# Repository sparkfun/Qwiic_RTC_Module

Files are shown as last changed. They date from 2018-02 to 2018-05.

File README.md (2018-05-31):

Qwiic Real Time Clock Module (RV-1805) Module
==================

Real Time Clock Module

[*Qwiic RV-1805 RTC Module (BOB-14558)*](https://www.sparkfun.com/products/14558)

Get with the times, already! This SparkFun Real Time Clock (RTC) Module is a Qwiic-enabled breakout board for the RV-1805 chipset. The RTC is ultra-low power (running at only about 22nA in its lowest power setting) so it can use a supercapacitor for backup power instead of a normal battery. This means you get plenty of charge and discharge cycles without any degradation to the “battery.“ To make it even easier to get your readings, all communication is enacted exclusively via I2C, utilizing our handy Qwiic system so no soldering is required to connect it to the rest of your system. However, we still have broken out 0.1”-spaced pins in case you prefer to use a breadboard.

Repository Contents
-------------------
* **/Documents** - Datasheets. 
* **/Hardware** - All Eagle design files (.brd, .sch). 
* **/Production** - Various test jigs and large panel layouts used for production.

Documentation
--------------
* **[Library](https://github.com/sparkfun/SparkFun_RV-1805_Arduino_Library)** - Arduino library for the Qwiic Real Time Clock Module (RV-1805) Module.
* **[Hookup Guide](https://learn.sparkfun.com/tutorials/qwiic-real-time-clock-module-rv-1805-hookup-guide)** - Basic hookup guide.

Product Versions
----------------
* [BOB-14558](https://www.sparkfun.com/products/14558) - SparkFun red version
* [SPX-14642](https://www.sparkfun.com/products/14642) - SparkX version

License Information
-------------------

This product is _**open source**_! 

Please review the LICENSE.md file for license information. 

If you have any questions or concerns on licensing, please contact techsupport@sparkfun.com.

Distributed as-is; no warranty is given.

- Your friends at SparkFun.

_<COLLABORATION CREDIT>_

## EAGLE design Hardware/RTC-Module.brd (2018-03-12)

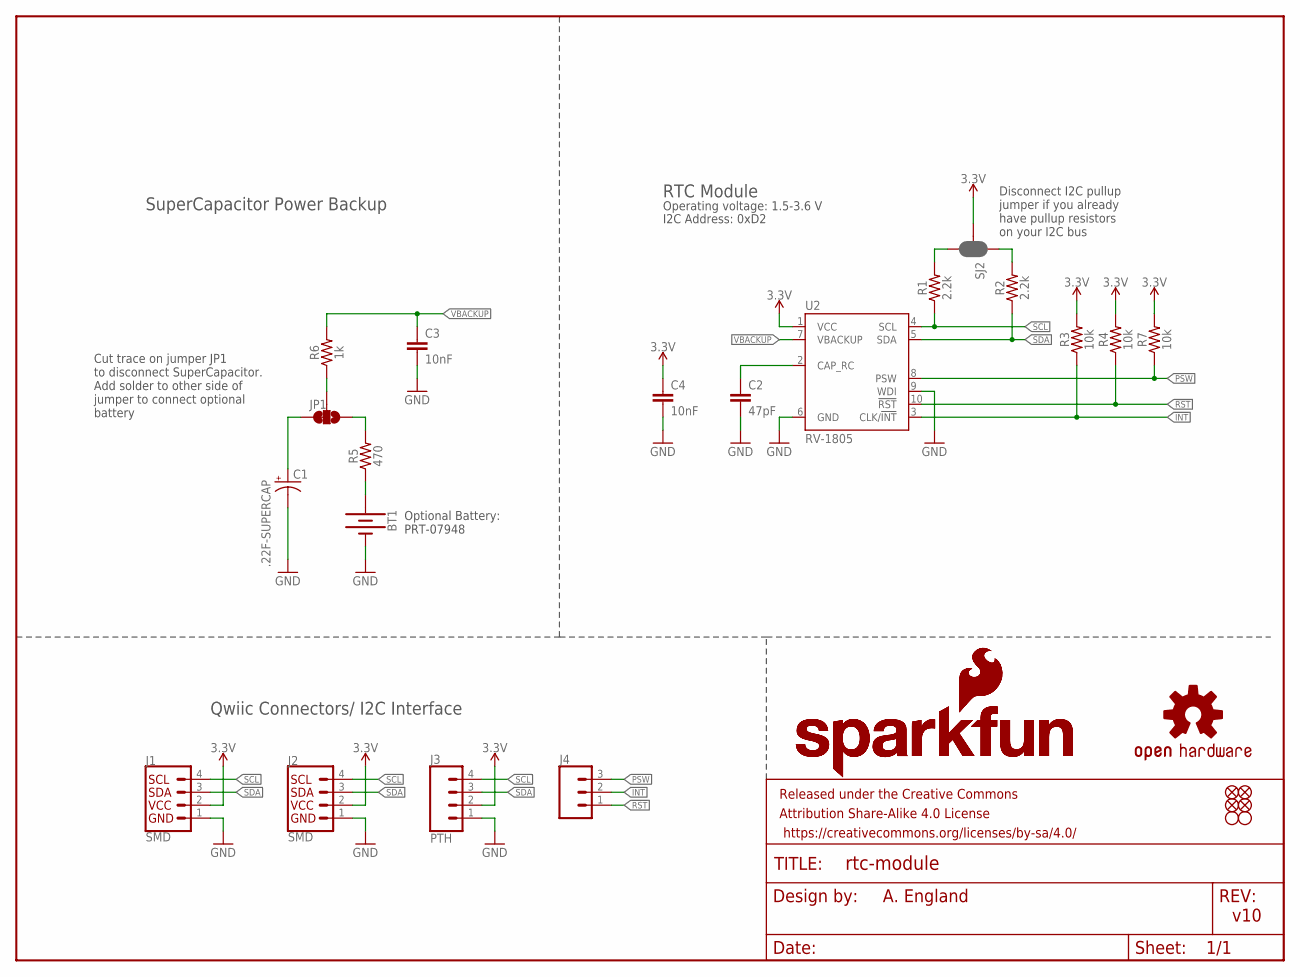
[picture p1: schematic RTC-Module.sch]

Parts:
BT1: BATTERY-12MM_PTH; BATTCON_12MM_PTH
C1: .22F-SUPERCAP; DSK-RADIAL-6.8MM
C2: 47pF; 0603
C3, C4: 10nF; 0603
FD1, FD2, FD3, FD4: FIDUCIALUFIDUCIAL; FIDUCIAL-MICRO
FRAME2: FRAME-LETTER; CREATIVE_COMMONS
J1, J2: SMD; 1X04_1MM_RA
J3: PTH; 1X04_NO_SILK
J4: CONN_031X03_NO_SILK; 1X03_NO_SILK
JP1: JUMPER-SMT_3_1-NC_TRACE_NO-SILK; SMT-JUMPER_3_1-NC_TRACE_NO-SILK
LOGO1: OSHW-LOGOS; OSHW-LOGO-S
LOGO2, LOGO3: SFE_LOGO_NAME_FLAME.1_INCH; SFE_LOGO_NAME_FLAME_.1
R1, R2: 2.2k; 0603
R3, R4, R7: 10k; 0603
R5: 470; 0603
R6: 1k; 0603
SJ2: JUMPER-SMT_3_2-NC_PASTE_SILK; SMT-JUMPER_3_2-NC_PASTE_SILK
U2: RV-1805
U$6, U$7: STAND-OFF

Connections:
3.3V: C4.1, J1.2, J2.2, J3.2, R3.2, R4.2, R7.2, SJ2.2, U2.1 (VCC)
!INT: J4.2, R3.1, U2.3 (CLK/!INT)
!RST: J4.1, R4.1, U2.10 (!RST)
GND: BT1.GND (-), C1.-, C2.2, C3.2, C4.2, J1.1, J2.1, J3.1, U2.6 (GND), U2.9 (WDI)
unnamed: R1.2, SJ2.3
unnamed: R2.2, SJ2.1
unnamed: BT1.VCC@1 (+), R5.1
unnamed: C2.1, U2.2 (CAP_RC)
unnamed: JP1.2, R6.1
unnamed: C1.+, JP1.3
unnamed: JP1.1, R5.2
PSW: J4.3, R7.1, U2.8 (PSW)
SCL: J1.4, J2.4, J3.4, R1.1, U2.4 (SCL)
SDA: J1.3, J2.3, J3.3, R2.1, U2.5 (SDA)
VBACKUP: C3.1, R6.2, U2.7 (VBACKUP)

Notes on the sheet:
v10
A. England
SuperCapacitor Power Backup
RTC Module
Qwiic Connectors/ I2C Interface
Cut trace on jumper JP1 to disconnect SuperCapacitor. Add solder to other side of jumper to connect optional battery
Operating voltage: 1.5-3.6 V
Disconnect I2C pullup jumper if you already have pullup resistors on your I2C bus
I2C Address: 0xD2
Optional Battery: PRT-07948

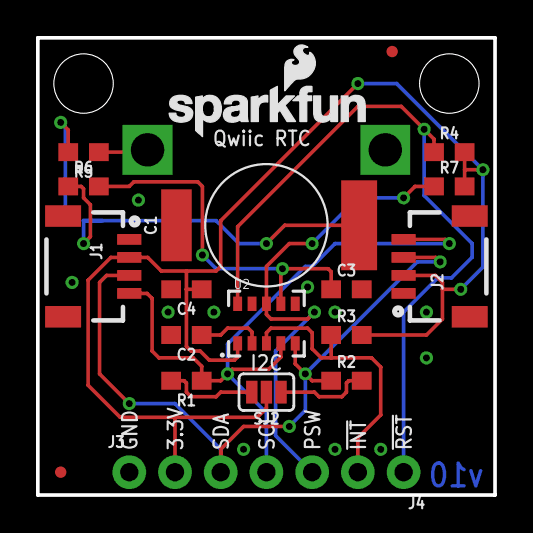
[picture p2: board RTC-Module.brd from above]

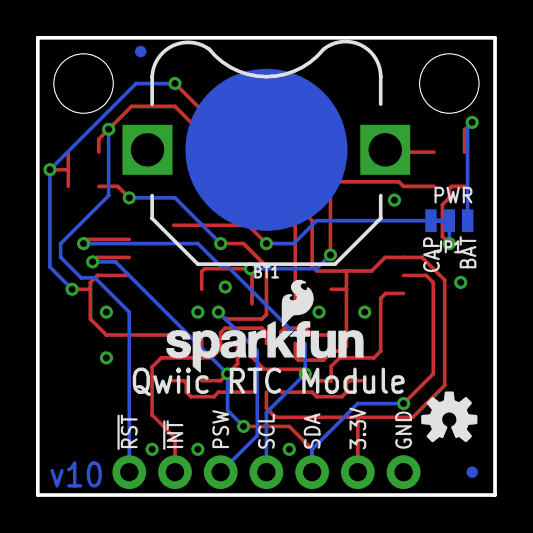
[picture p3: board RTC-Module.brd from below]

Board: 2 copper layers, 25.4 x 25.4 mm, 29 parts (6 on the bottom side), 15 nets.

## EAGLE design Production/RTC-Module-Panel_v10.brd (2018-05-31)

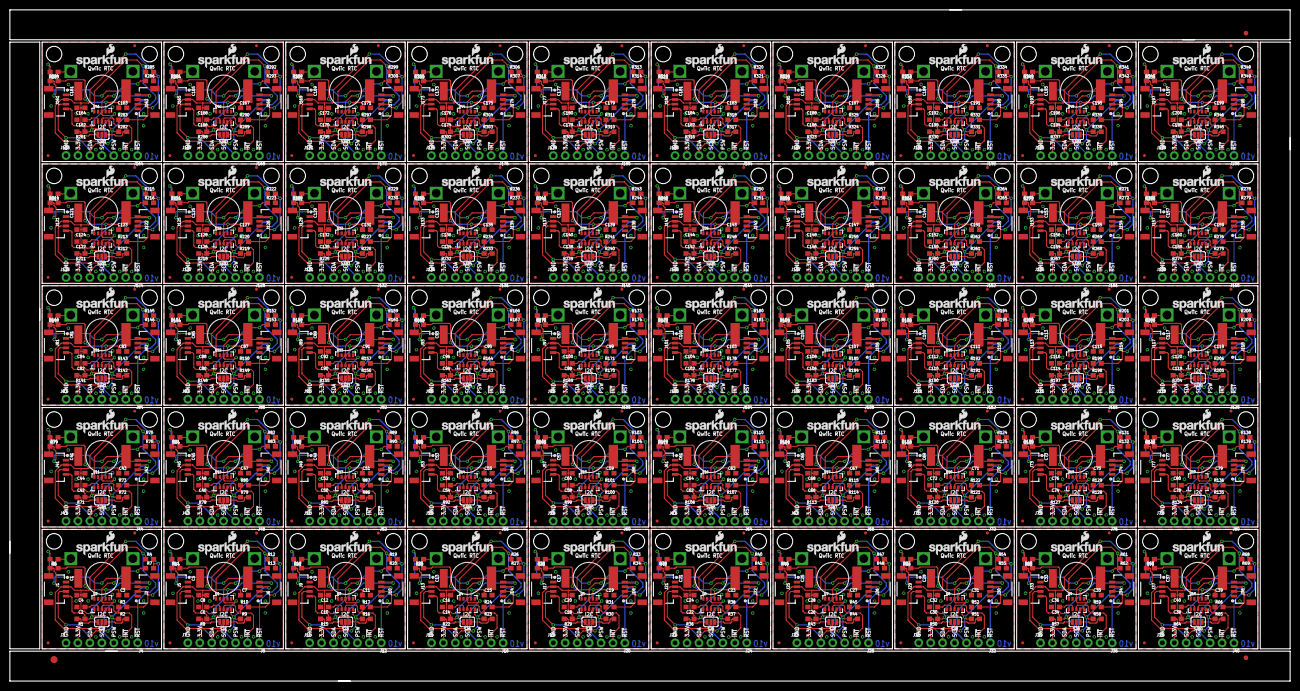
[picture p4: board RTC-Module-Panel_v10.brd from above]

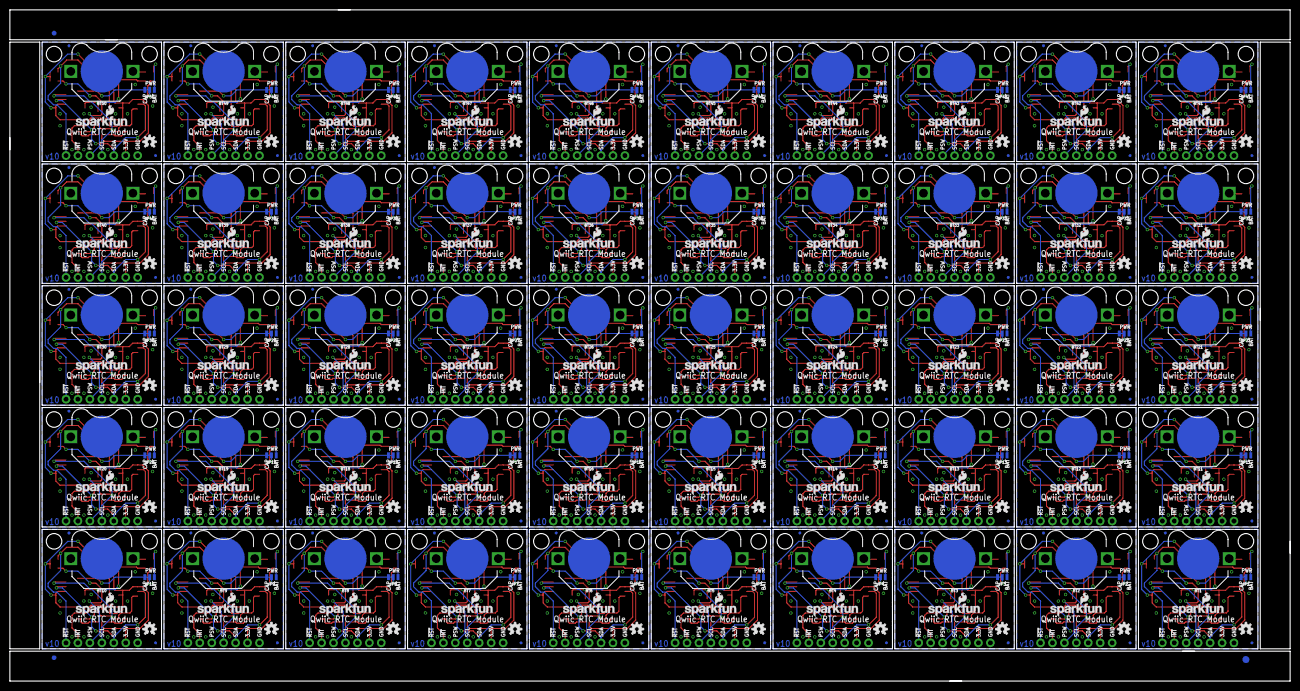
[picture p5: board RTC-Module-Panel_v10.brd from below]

Board: 2 copper layers, 272.3 x 142.7 mm, 1406 parts (303 on the bottom side), 750 nets.

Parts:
BT1, BT2, BT3, BT4, BT5, BT6, BT7, BT8, BT9, BT10, BT11, BT12, BT13, BT14, BT15, BT16, BT17, BT18, BT19, BT20, BT21, BT22, BT23, BT24, BT25, BT26, BT27, BT28, BT29, BT30, BT31, BT32, BT33, BT34, BT35, BT36, BT37, BT38, BT39, BT40, BT41, BT42, BT43, BT44, BT45, BT46, BT47, BT48, BT49, BT50: BATTCON_12MM_PTH
C1, C5, C9, C13, C17, C21, C25, C29, C33, C37, C41, C45, C49, C53, C57, C61, C65, C69, C73, C77, C81, C85, C89, C93, C97, C101, C105, C109, C113, C117, C121, C125, C129, C133, C137, C141, C145, C149, C153, C157, C161, C165, C169, C173, C177, C181, C185, C189, C193, C197: .22F-SUPERCAP; DSK-RADIAL-6.8MM
C2, C6, C10, C14, C18, C22, C26, C30, C34, C38, C42, C46, C50, C54, C58, C62, C66, C70, C74, C78, C82, C86, C90, C94, C98, C102, C106, C110, C114, C118, C122, C126, C130, C134, C138, C142, C146, C150, C154, C158, C162, C166, C170, C174, C178, C182, C186, C190, C194, C198: 47pF; 0603
C3, C4, C7, C8, C11, C12, C15, C16, C19, C20, C23, C24, C27, C28, C31, C32, C35, C36, C39, C40, C43, C44, C47, C48, C51, C52, C55, C56, C59, C60, C63, C64, C67, C68, C71, C72, C75, C76, C79, C80, C83, C84, C87, C88, C91, C92, C95, C96, C99, C100, C103, C104, C107, C108, C111, C112, C115, C116, C119, C120, C123, C124, C127, C128, C131, C132, C135, C136, C139, C140, C143, C144, C147, C148, C151, C152, C155, C156, C159, C160, C163, C164, C167, C168, C171, C172, C175, C176, C179, C180, C183, C184, C187, C188, C191, C192, C195, C196, C199, C200: 10nF; 0603
E$1, E$2: FIDUCIAL-1.5X3
E$3, E$4, E$6, E$7: FIDUCIAL-1X2
FD1, FD2, FD3, FD4, FD5, FD6, FD7, FD8, FD9, FD10, FD11, FD12, FD13, FD14, FD15, FD16, FD17, FD18, FD19, FD20, FD21, FD22, FD23, FD24, FD25, FD26, FD27, FD28, FD29, FD30, FD31, FD32, FD33, FD34, FD35, FD36, FD37, FD38, FD39, FD40, FD41, FD42, FD43, FD44, FD45, FD46, FD47, FD48, FD49, FD50, FD51, FD52, FD53, FD54, FD55, FD56, FD57, FD58, FD59, FD60, FD61, FD62, FD63, FD64, FD65, FD66, FD67, FD68, FD69, FD70, FD71, FD72, FD73, FD74, FD75, FD76, FD77, FD78, FD79, FD80, FD81, FD82, FD83, FD84, FD85, FD86, FD87, FD88, FD89, FD90, FD91, FD92, FD93, FD94, FD95, FD96, FD97, FD98, FD99, FD100, FD101, FD102, FD103, FD104, FD105, FD106, FD107, FD108, FD109, FD110, FD111, FD112, FD113, FD114, FD115, FD116, FD117, FD118, FD119, FD120, FD121, FD122, FD123, FD124, FD125, FD126, FD127, FD128, FD129, FD130, FD131, FD132, FD133, FD134, FD135, FD136, FD137, FD138, FD139, FD140, FD141, FD142, FD143, FD144, FD145, FD146, FD147, FD148, FD149, FD150, FD151, FD152, FD153, FD154, FD155, FD156, FD157, FD158, FD159, FD160, FD161, FD162, FD163, FD164, FD165, FD166, FD167, FD168, FD169, FD170, FD171, FD172, FD173, FD174, FD175, FD176, FD177, FD178, FD179, FD180, FD181, FD182, FD183, FD184, FD185, FD186, FD187, FD188, FD189, FD190, FD191, FD192, FD193, FD194, FD195, FD196, FD197, FD198, FD199, FD200: FIDUCIALUFIDUCIAL; FIDUCIAL-MICRO
J1, J2, J5, J6, J9, J10, J13, J14, J17, J18, J21, J22, J25, J26, J29, J30, J33, J34, J37, J38, J41, J42, J45, J46, J49, J50, J53, J54, J57, J58, J61, J62, J65, J66, J69, J70, J73, J74, J77, J78, J81, J82, J85, J86, J89, J90, J93, J94, J97, J98, J101, J102, J105, J106, J109, J110, J113, J114, J117, J118, J121, J122, J125, J126, J129, J130, J133, J134, J137, J138, J141, J142, J145, J146, J149, J150, J153, J154, J157, J158, J161, J162, J165, J166, J169, J170, J173, J174, J177, J178, J181, J182, J185, J186, J189, J190, J193, J194, J197, J198: SMD; 1X04_1MM_RA
J3, J7, J11, J15, J19, J23, J27, J31, J35, J39, J43, J47, J51, J55, J59, J63, J67, J71, J75, J79, J83, J87, J91, J95, J99, J103, J107, J111, J115, J119, J123, J127, J131, J135, J139, J143, J147, J151, J155, J159, J163, J167, J171, J175, J179, J183, J187, J191, J195, J199: PTH; 1X04_NO_SILK
J4, J8, J12, J16, J20, J24, J28, J32, J36, J40, J44, J48, J52, J56, J60, J64, J68, J72, J76, J80, J84, J88, J92, J96, J100, J104, J108, J112, J116, J120, J124, J128, J132, J136, J140, J144, J148, J152, J156, J160, J164, J168, J172, J176, J180, J184, J188, J192, J196, J200: 1X03_NO_SILK
JP1, JP2, JP3, JP4, JP5, JP6, JP7, JP8, JP9, JP10, JP11, JP12, JP13, JP14, JP15, JP16, JP17, JP18, JP19, JP20, JP21, JP22, JP23, JP24, JP25, JP26, JP27, JP28, JP29, JP30, JP31, JP32, JP33, JP34, JP35, JP36, JP37, JP38, JP39, JP40, JP41, JP42, JP43, JP44, JP45, JP46, JP47, JP48, JP49, JP50: JUMPER-SMT_3_1-NC_TRACE_NO-SILK; SMT-JUMPER_3_1-NC_TRACE_NO-SILK
LOGO1, LOGO4, LOGO7, LOGO10, LOGO13, LOGO16, LOGO19, LOGO22, LOGO25, LOGO28, LOGO31, LOGO34, LOGO37, LOGO40, LOGO43, LOGO46, LOGO49, LOGO52, LOGO55, LOGO58, LOGO61, LOGO64, LOGO67, LOGO70, LOGO73, LOGO76, LOGO79, LOGO82, LOGO85, LOGO88, LOGO91, LOGO94, LOGO97, LOGO100, LOGO103, LOGO106, LOGO109, LOGO112, LOGO115, LOGO118, LOGO121, LOGO124, LOGO127, LOGO130, LOGO133, LOGO136, LOGO139, LOGO142, LOGO145, LOGO148: OSHW-LOGOS; OSHW-LOGO-S
LOGO2, LOGO3, LOGO5, LOGO6, LOGO8, LOGO9, LOGO11, LOGO12, LOGO14, LOGO15, LOGO17, LOGO18, LOGO20, LOGO21, LOGO23, LOGO24, LOGO26, LOGO27, LOGO29, LOGO30, LOGO32, LOGO33, LOGO35, LOGO36, LOGO38, LOGO39, LOGO41, LOGO42, LOGO44, LOGO45, LOGO47, LOGO48, LOGO50, LOGO51, LOGO53, LOGO54, LOGO56, LOGO57, LOGO59, LOGO60, LOGO62, LOGO63, LOGO65, LOGO66, LOGO68, LOGO69, LOGO71, LOGO72, LOGO74, LOGO75, LOGO77, LOGO78, LOGO80, LOGO81, LOGO83, LOGO84, LOGO86, LOGO87, LOGO89, LOGO90, LOGO92, LOGO93, LOGO95, LOGO96, LOGO98, LOGO99, LOGO101, LOGO102, LOGO104, LOGO105, LOGO107, LOGO108, LOGO110, LOGO111, LOGO113, LOGO114, LOGO116, LOGO117, LOGO119, LOGO120, LOGO122, LOGO123, LOGO125, LOGO126, LOGO128, LOGO129, LOGO131, LOGO132, LOGO134, LOGO135, LOGO137, LOGO138, LOGO140, LOGO141, LOGO143, LOGO144, LOGO146, LOGO147, LOGO149, LOGO150: SFE_LOGO_NAME_FLAME.1_INCH; SFE_LOGO_NAME_FLAME_.1
R1, R2, R8, R9, R15, R16, R22, R23, R29, R30, R36, R37, R43, R44, R50, R51, R57, R58, R64, R65, R71, R72, R78, R79, R85, R86, R92, R93, R99, R100, R106, R107, R113, R114, R120, R121, R127, R128, R134, R135, R141, R142, R148, R149, R155, R156, R162, R163, R169, R170, R176, R177, R183, R184, R190, R191, R197, R198, R204, R205, R211, R212, R218, R219, R225, R226, R232, R233, R239, R240, R246, R247, R253, R254, R260, R261, R267, R268, R274, R275, R281, R282, R288, R289, R295, R296, R302, R303, R309, R310, R316, R317, R323, R324, R330, R331, R337, R338, R344, R345: 2.2k; 0603
R3, R4, R7, R10, R12, R13, R17, R19, R20, R24, R26, R27, R31, R33, R34, R38, R40, R41, R45, R47, R48, R52, R54, R55, R59, R61, R62, R66, R68, R69, R73, R75, R76, R80, R82, R83, R87, R89, R90, R94, R96, R97, R101, R103, R104, R108, R110, R111, R115, R117, R118, R122, R124, R125, R129, R131, R132, R136, R138, R139, R143, R145, R146, R150, R152, R153, R157, R159, R160, R164, R166, R167, R171, R173, R174, R178, R180, R181, R185, R187, R188, R192, R194, R195, R199, R201, R202, R206, R208, R209, R213, R215, R216, R220, R222, R223, R227, R229, R230, R234, R236, R237, R241, R243, R244, R248, R250, R251, R255, R257, R258, R262, R264, R265, R269, R271, R272, R276, R278, R279, R283, R285, R286, R290, R292, R293, R297, R299, R300, R304, R306, R307, R311, R313, R314, R318, R320, R321, R325, R327, R328, R332, R334, R335, R339, R341, R342, R346, R348, R349: 10k; 0603
R5, R14, R21, R28, R35, R42, R49, R56, R63, R70, R77, R84, R91, R98, R105, R112, R119, R126, R133, R140, R147, R154, R161, R168, R175, R182, R189, R196, R203, R210, R217, R224, R231, R238, R245, R252, R259, R266, R273, R280, R287, R294, R301, R308, R315, R322, R329, R336, R343, R350: 470; 0603
R6, R11, R18, R25, R32, R39, R46, R53, R60, R67, R74, R81, R88, R95, R102, R109, R116, R123, R130, R137, R144, R151, R158, R165, R172, R179, R186, R193, R200, R207, R214, R221, R228, R235, R242, R249, R256, R263, R270, R277, R284, R291, R298, R305, R312, R319, R326, R333, R340, R347: 1k; 0603
SJ1, SJ2, SJ3, SJ4, SJ5, SJ6, SJ7, SJ8, SJ9, SJ10, SJ11, SJ12, SJ13, SJ14, SJ15, SJ16, SJ17, SJ18, SJ19, SJ20, SJ21, SJ22, SJ23, SJ24, SJ25, SJ26, SJ27, SJ28, SJ29, SJ30, SJ31, SJ32, SJ33, SJ34, SJ35, SJ36, SJ37, SJ38, SJ39, SJ40, SJ41, SJ42, SJ43, SJ44, SJ45, SJ46, SJ47, SJ48, SJ49, SJ50: JUMPER-SMT_3_2-NC_PASTE_SILK; SMT-JUMPER_3_2-NC_PASTE_SILK
U1, U2, U3, U4, U5, U6, U7, U8, U9, U10, U11, U12, U13, U14, U15, U16, U17, U18, U19, U20, U21, U22, U23, U24, U25, U26, U27, U28, U29, U30, U31, U32, U33, U34, U35, U36, U37, U38, U39, U40, U41, U42, U43, U44, U45, U46, U47, U48, U49, U50: RV-1805
U$1, U$2, U$3, U$4, U$5, U$6, U$7, U$8, U$9, U$10, U$11, U$12, U$13, U$14, U$15, U$16, U$17, U$18, U$19, U$20, U$21, U$22, U$23, U$24, U$25, U$26, U$27, U$28, U$29, U$30, U$31, U$32, U$33, U$34, U$35, U$36, U$37, U$38, U$39, U$40, U$41, U$42, U$43, U$44, U$45, U$46, U$47, U$48, U$49, U$50, U$51, U$52, U$53, U$54, U$55, U$56, U$57, U$58, U$59, U$60, U$61, U$62, U$63, U$64, U$65, U$66, U$67, U$68, U$69, U$70, U$71, U$72, U$73, U$74, U$75, U$76, U$77, U$78, U$79, U$80, U$81, U$82, U$83, U$84, U$85, U$86, U$87, U$88, U$89, U$90, U$91, U$92, U$93, U$94, U$95, U$96, U$97, U$98, U$99, U$100: STAND-OFF

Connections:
3.3V: C4.1, J1.2, J2.2, J3.2, R3.2, R4.2, R7.2, SJ2.2, U2.1
3.3V1: C8.1, J5.2, J6.2, J7.2, R10.2, R12.2, R13.2, SJ1.2, U1.1
3.3V2: C12.1, J9.2, J10.2, J11.2, R17.2, R19.2, R20.2, SJ3.2, U3.1
3.3V3: C16.1, J13.2, J14.2, J15.2, R24.2, R26.2, R27.2, SJ4.2, U4.1
3.3V4: C20.1, J17.2, J18.2, J19.2, R31.2, R33.2, R34.2, SJ5.2, U5.1
3.3V5: C24.1, J21.2, J22.2, J23.2, R38.2, R40.2, R41.2, SJ6.2, U6.1
3.3V6: C28.1, J25.2, J26.2, J27.2, R45.2, R47.2, R48.2, SJ7.2, U7.1
3.3V7: C32.1, J29.2, J30.2, J31.2, R52.2, R54.2, R55.2, SJ8.2, U8.1
3.3V8: C36.1, J33.2, J34.2, J35.2, R59.2, R61.2, R62.2, SJ9.2, U9.1
3.3V9: C40.1, J37.2, J38.2, J39.2, R66.2, R68.2, R69.2, SJ10.2, U10.1
3.3V10: C44.1, J41.2, J42.2, J43.2, R73.2, R75.2, R76.2, SJ11.2, U11.1
3.3V11: C48.1, J45.2, J46.2, J47.2, R80.2, R82.2, R83.2, SJ12.2, U12.1
3.3V12: C52.1, J49.2, J50.2, J51.2, R87.2, R89.2, R90.2, SJ13.2, U13.1
3.3V13: C56.1, J53.2, J54.2, J55.2, R94.2, R96.2, R97.2, SJ14.2, U14.1
3.3V14: C60.1, J57.2, J58.2, J59.2, R101.2, R103.2, R104.2, SJ15.2, U15.1
3.3V15: C64.1, J61.2, J62.2, J63.2, R108.2, R110.2, R111.2, SJ16.2, U16.1
3.3V16: C68.1, J65.2, J66.2, J67.2, R115.2, R117.2, R118.2, SJ17.2, U17.1
3.3V17: C72.1, J69.2, J70.2, J71.2, R122.2, R124.2, R125.2, SJ18.2, U18.1
3.3V18: C76.1, J73.2, J74.2, J75.2, R129.2, R131.2, R132.2, SJ19.2, U19.1
3.3V19: C80.1, J77.2, J78.2, J79.2, R136.2, R138.2, R139.2, SJ20.2, U20.1
3.3V20: C84.1, J81.2, J82.2, J83.2, R143.2, R145.2, R146.2, SJ21.2, U21.1
3.3V21: C88.1, J85.2, J86.2, J87.2, R150.2, R152.2, R153.2, SJ22.2, U22.1
3.3V22: C92.1, J89.2, J90.2, J91.2, R157.2, R159.2, R160.2, SJ23.2, U23.1
3.3V23: C96.1, J93.2, J94.2, J95.2, R164.2, R166.2, R167.2, SJ24.2, U24.1
3.3V24: C100.1, J97.2, J98.2, J99.2, R171.2, R173.2, R174.2, SJ25.2, U25.1
3.3V25: C104.1, J101.2, J102.2, J103.2, R178.2, R180.2, R181.2, SJ26.2, U26.1
3.3V26: C108.1, J105.2, J106.2, J107.2, R185.2, R187.2, R188.2, SJ27.2, U27.1
3.3V27: C112.1, J109.2, J110.2, J111.2, R192.2, R194.2, R195.2, SJ28.2, U28.1
3.3V28: C116.1, J113.2, J114.2, J115.2, R199.2, R201.2, R202.2, SJ29.2, U29.1
3.3V29: C120.1, J117.2, J118.2, J119.2, R206.2, R208.2, R209.2, SJ30.2, U30.1
3.3V30: C124.1, J121.2, J122.2, J123.2, R213.2, R215.2, R216.2, SJ31.2, U31.1
3.3V31: C128.1, J125.2, J126.2, J127.2, R220.2, R222.2, R223.2, SJ32.2, U32.1
3.3V32: C132.1, J129.2, J130.2, J131.2, R227.2, R229.2, R230.2, SJ33.2, U33.1
3.3V33: C136.1, J133.2, J134.2, J135.2, R234.2, R236.2, R237.2, SJ34.2, U34.1
3.3V34: C140.1, J137.2, J138.2, J139.2, R241.2, R243.2, R244.2, SJ35.2, U35.1
3.3V35: C144.1, J141.2, J142.2, J143.2, R248.2, R250.2, R251.2, SJ36.2, U36.1
3.3V36: C148.1, J145.2, J146.2, J147.2, R255.2, R257.2, R258.2, SJ37.2, U37.1
3.3V37: C152.1, J149.2, J150.2, J151.2, R262.2, R264.2, R265.2, SJ38.2, U38.1
3.3V38: C156.1, J153.2, J154.2, J155.2, R269.2, R271.2, R272.2, SJ39.2, U39.1
3.3V39: C160.1, J157.2, J158.2, J159.2, R276.2, R278.2, R279.2, SJ40.2, U40.1
3.3V40: C164.1, J161.2, J162.2, J163.2, R283.2, R285.2, R286.2, SJ41.2, U41.1
3.3V41: C168.1, J165.2, J166.2, J167.2, R290.2, R292.2, R293.2, SJ42.2, U42.1
3.3V42: C172.1, J169.2, J170.2, J171.2, R297.2, R299.2, R300.2, SJ43.2, U43.1
3.3V43: C176.1, J173.2, J174.2, J175.2, R304.2, R306.2, R307.2, SJ44.2, U44.1
3.3V44: C180.1, J177.2, J178.2, J179.2, R311.2, R313.2, R314.2, SJ45.2, U45.1
3.3V45: C184.1, J181.2, J182.2, J183.2, R318.2, R320.2, R321.2, SJ46.2, U46.1
3.3V46: C188.1, J185.2, J186.2, J187.2, R325.2, R327.2, R328.2, SJ47.2, U47.1
3.3V47: C192.1, J189.2, J190.2, J191.2, R332.2, R334.2, R335.2, SJ48.2, U48.1
3.3V48: C196.1, J193.2, J194.2, J195.2, R339.2, R341.2, R342.2, SJ49.2, U49.1
3.3V49: C200.1, J197.2, J198.2, J199.2, R346.2, R348.2, R349.2, SJ50.2, U50.1
!INT: J4.2, R3.1, U2.3
!INT1: J8.2, R10.1, U1.3
!INT2: J12.2, R17.1, U3.3
!INT3: J16.2, R24.1, U4.3
!INT4: J20.2, R31.1, U5.3
!INT5: J24.2, R38.1, U6.3
!INT6: J28.2, R45.1, U7.3
!INT7: J32.2, R52.1, U8.3
!INT8: J36.2, R59.1, U9.3
!INT9: J40.2, R66.1, U10.3
!INT10: J44.2, R73.1, U11.3
!INT11: J48.2, R80.1, U12.3
!INT12: J52.2, R87.1, U13.3
!INT13: J56.2, R94.1, U14.3
!INT14: J60.2, R101.1, U15.3
!INT15: J64.2, R108.1, U16.3
!INT16: J68.2, R115.1, U17.3
!INT17: J72.2, R122.1, U18.3
!INT18: J76.2, R129.1, U19.3
!INT19: J80.2, R136.1, U20.3
!INT20: J84.2, R143.1, U21.3
!INT21: J88.2, R150.1, U22.3
!INT22: J92.2, R157.1, U23.3
!INT23: J96.2, R164.1, U24.3
!INT24: J100.2, R171.1, U25.3
!INT25: J104.2, R178.1, U26.3
!INT26: J108.2, R185.1, U27.3
!INT27: J112.2, R192.1, U28.3
!INT28: J116.2, R199.1, U29.3
!INT29: J120.2, R206.1, U30.3
!INT30: J124.2, R213.1, U31.3
!INT31: J128.2, R220.1, U32.3
!INT32: J132.2, R227.1, U33.3
!INT33: J136.2, R234.1, U34.3
!INT34: J140.2, R241.1, U35.3
!INT35: J144.2, R248.1, U36.3
!INT36: J148.2, R255.1, U37.3
!INT37: J152.2, R262.1, U38.3
!INT38: J156.2, R269.1, U39.3
!INT39: J160.2, R276.1, U40.3
!INT40: J164.2, R283.1, U41.3
!INT41: J168.2, R290.1, U42.3
!INT42: J172.2, R297.1, U43.3
!INT43: J176.2, R304.1, U44.3
!INT44: J180.2, R311.1, U45.3
!INT45: J184.2, R318.1, U46.3
!INT46: J188.2, R325.1, U47.3
!INT47: J192.2, R332.1, U48.3
!INT48: J196.2, R339.1, U49.3
!INT49: J200.2, R346.1, U50.3
!RST: J4.1, R4.1, U2.10
!RST1: J8.1, R12.1, U1.10
!RST2: J12.1, R19.1, U3.10
!RST3: J16.1, R26.1, U4.10
!RST4: J20.1, R33.1, U5.10
!RST5: J24.1, R40.1, U6.10
!RST6: J28.1, R47.1, U7.10
!RST7: J32.1, R54.1, U8.10
!RST8: J36.1, R61.1, U9.10
!RST9: J40.1, R68.1, U10.10
!RST10: J44.1, R75.1, U11.10
!RST11: J48.1, R82.1, U12.10
!RST12: J52.1, R89.1, U13.10
!RST13: J56.1, R96.1, U14.10
!RST14: J60.1, R103.1, U15.10
!RST15: J64.1, R110.1, U16.10
!RST16: J68.1, R117.1, U17.10
!RST17: J72.1, R124.1, U18.10
!RST18: J76.1, R131.1, U19.10
!RST19: J80.1, R138.1, U20.10
!RST20: J84.1, R145.1, U21.10
!RST21: J88.1, R152.1, U22.10
!RST22: J92.1, R159.1, U23.10
!RST23: J96.1, R166.1, U24.10
!RST24: J100.1, R173.1, U25.10
!RST25: J104.1, R180.1, U26.10
!RST26: J108.1, R187.1, U27.10
!RST27: J112.1, R194.1, U28.10
!RST28: J116.1, R201.1, U29.10
!RST29: J120.1, R208.1, U30.10
!RST30: J124.1, R215.1, U31.10
!RST31: J128.1, R222.1, U32.10
!RST32: J132.1, R229.1, U33.10
!RST33: J136.1, R236.1, U34.10
!RST34: J140.1, R243.1, U35.10
!RST35: J144.1, R250.1, U36.10
!RST36: J148.1, R257.1, U37.10
!RST37: J152.1, R264.1, U38.10
!RST38: J156.1, R271.1, U39.10
!RST39: J160.1, R278.1, U40.10
!RST40: J164.1, R285.1, U41.10
!RST41: J168.1, R292.1, U42.10
!RST42: J172.1, R299.1, U43.10
!RST43: J176.1, R306.1, U44.10
!RST44: J180.1, R313.1, U45.10
!RST45: J184.1, R320.1, U46.10
!RST46: J188.1, R327.1, U47.10
!RST47: J192.1, R334.1, U48.10
!RST48: J196.1, R341.1, U49.10
!RST49: J200.1, R348.1, U50.10
GND: BT1.GND, C1.-, C2.2, C3.2, C4.2, J1.1, J2.1, J3.1, U2.6, U2.9
GND1: BT2.GND, C5.-, C6.2, C7.2, C8.2, J5.1, J6.1, J7.1, U1.6, U1.9
GND2: BT3.GND, C9.-, C10.2, C11.2, C12.2, J9.1, J10.1, J11.1, U3.6, U3.9
GND3: BT4.GND, C13.-, C14.2, C15.2, C16.2, J13.1, J14.1, J15.1, U4.6, U4.9
GND4: BT5.GND, C17.-, C18.2, C19.2, C20.2, J17.1, J18.1, J19.1, U5.6, U5.9
GND5: BT6.GND, C21.-, C22.2, C23.2, C24.2, J21.1, J22.1, J23.1, U6.6, U6.9
GND6: BT7.GND, C25.-, C26.2, C27.2, C28.2, J25.1, J26.1, J27.1, U7.6, U7.9
GND7: BT8.GND, C29.-, C30.2, C31.2, C32.2, J29.1, J30.1, J31.1, U8.6, U8.9
GND8: BT9.GND, C33.-, C34.2, C35.2, C36.2, J33.1, J34.1, J35.1, U9.6, U9.9
GND9: BT10.GND, C37.-, C38.2, C39.2, C40.2, J37.1, J38.1, J39.1, U10.6, U10.9
GND10: BT11.GND, C41.-, C42.2, C43.2, C44.2, J41.1, J42.1, J43.1, U11.6, U11.9
GND11: BT12.GND, C45.-, C46.2, C47.2, C48.2, J45.1, J46.1, J47.1, U12.6, U12.9
GND12: BT13.GND, C49.-, C50.2, C51.2, C52.2, J49.1, J50.1, J51.1, U13.6, U13.9
GND13: BT14.GND, C53.-, C54.2, C55.2, C56.2, J53.1, J54.1, J55.1, U14.6, U14.9
GND14: BT15.GND, C57.-, C58.2, C59.2, C60.2, J57.1, J58.1, J59.1, U15.6, U15.9
GND15: BT16.GND, C61.-, C62.2, C63.2, C64.2, J61.1, J62.1, J63.1, U16.6, U16.9
GND16: BT17.GND, C65.-, C66.2, C67.2, C68.2, J65.1, J66.1, J67.1, U17.6, U17.9
GND17: BT18.GND, C69.-, C70.2, C71.2, C72.2, J69.1, J70.1, J71.1, U18.6, U18.9
GND18: BT19.GND, C73.-, C74.2, C75.2, C76.2, J73.1, J74.1, J75.1, U19.6, U19.9
GND19: BT20.GND, C77.-, C78.2, C79.2, C80.2, J77.1, J78.1, J79.1, U20.6, U20.9
GND20: BT21.GND, C81.-, C82.2, C83.2, C84.2, J81.1, J82.1, J83.1, U21.6, U21.9
GND21: BT22.GND, C85.-, C86.2, C87.2, C88.2, J85.1, J86.1, J87.1, U22.6, U22.9
GND22: BT23.GND, C89.-, C90.2, C91.2, C92.2, J89.1, J90.1, J91.1, U23.6, U23.9
GND23: BT24.GND, C93.-, C94.2, C95.2, C96.2, J93.1, J94.1, J95.1, U24.6, U24.9
GND24: BT25.GND, C97.-, C98.2, C99.2, C100.2, J97.1, J98.1, J99.1, U25.6, U25.9
GND25: BT26.GND, C101.-, C102.2, C103.2, C104.2, J101.1, J102.1, J103.1, U26.6, U26.9
GND26: BT27.GND, C105.-, C106.2, C107.2, C108.2, J105.1, J106.1, J107.1, U27.6, U27.9
GND27: BT28.GND, C109.-, C110.2, C111.2, C112.2, J109.1, J110.1, J111.1, U28.6, U28.9
GND28: BT29.GND, C113.-, C114.2, C115.2, C116.2, J113.1, J114.1, J115.1, U29.6, U29.9
GND29: BT30.GND, C117.-, C118.2, C119.2, C120.2, J117.1, J118.1, J119.1, U30.6, U30.9
GND30: BT31.GND, C121.-, C122.2, C123.2, C124.2, J121.1, J122.1, J123.1, U31.6, U31.9
GND31: BT32.GND, C125.-, C126.2, C127.2, C128.2, J125.1, J126.1, J127.1, U32.6, U32.9
GND32: BT33.GND, C129.-, C130.2, C131.2, C132.2, J129.1, J130.1, J131.1, U33.6, U33.9
GND33: BT34.GND, C133.-, C134.2, C135.2, C136.2, J133.1, J134.1, J135.1, U34.6, U34.9
GND34: BT35.GND, C137.-, C138.2, C139.2, C140.2, J137.1, J138.1, J139.1, U35.6, U35.9
GND35: BT36.GND, C141.-, C142.2, C143.2, C144.2, J141.1, J142.1, J143.1, U36.6, U36.9
GND36: BT37.GND, C145.-, C146.2, C147.2, C148.2, J145.1, J146.1, J147.1, U37.6, U37.9
GND37: BT38.GND, C149.-, C150.2, C151.2, C152.2, J149.1, J150.1, J151.1, U38.6, U38.9
GND38: BT39.GND, C153.-, C154.2, C155.2, C156.2, J153.1, J154.1, J155.1, U39.6, U39.9
GND39: BT40.GND, C157.-, C158.2, C159.2, C160.2, J157.1, J158.1, J159.1, U40.6, U40.9
GND40: BT41.GND, C161.-, C162.2, C163.2, C164.2, J161.1, J162.1, J163.1, U41.6, U41.9
GND41: BT42.GND, C165.-, C166.2, C167.2, C168.2, J165.1, J166.1, J167.1, U42.6, U42.9
GND42: BT43.GND, C169.-, C170.2, C171.2, C172.2, J169.1, J170.1, J171.1, U43.6, U43.9
GND43: BT44.GND, C173.-, C174.2, C175.2, C176.2, J173.1, J174.1, J175.1, U44.6, U44.9
GND44: BT45.GND, C177.-, C178.2, C179.2, C180.2, J177.1, J178.1, J179.1, U45.6, U45.9
GND45: BT46.GND, C181.-, C182.2, C183.2, C184.2, J181.1, J182.1, J183.1, U46.6, U46.9
GND46: BT47.GND, C185.-, C186.2, C187.2, C188.2, J185.1, J186.1, J187.1, U47.6, U47.9
GND47: BT48.GND, C189.-, C190.2, C191.2, C192.2, J189.1, J190.1, J191.1, U48.6, U48.9
GND48: BT49.GND, C193.-, C194.2, C195.2, C196.2, J193.1, J194.1, J195.1, U49.6, U49.9
GND49: BT50.GND, C197.-, C198.2, C199.2, C200.2, J197.1, J198.1, J199.1, U50.6, U50.9
unnamed: R1.2, SJ2.3
unnamed: R2.2, SJ2.1
unnamed: BT1.VCC@1, R5.1
unnamed: C2.1, U2.2
unnamed: JP1.2, R6.1
unnamed: C1.+, JP1.3
unnamed: JP1.1, R5.2
unnamed: R8.2, SJ1.3
unnamed: R9.2, SJ1.1
unnamed: C6.1, U1.2
unnamed: BT2.VCC@1, R14.1
unnamed: JP2.2, R11.1
unnamed: C5.+, JP2.3
unnamed: JP2.1, R14.2
unnamed: R15.2, SJ3.3
unnamed: R16.2, SJ3.1
unnamed: C10.1, U3.2
unnamed: BT3.VCC@1, R21.1
unnamed: JP3.2, R18.1
unnamed: C9.+, JP3.3
unnamed: JP3.1, R21.2
unnamed: R22.2, SJ4.3
unnamed: R23.2, SJ4.1
unnamed: C14.1, U4.2
unnamed: BT4.VCC@1, R28.1
unnamed: JP4.2, R25.1
unnamed: C13.+, JP4.3
unnamed: JP4.1, R28.2
unnamed: R29.2, SJ5.3
unnamed: R30.2, SJ5.1
unnamed: C18.1, U5.2
unnamed: BT5.VCC@1, R35.1
unnamed: JP5.2, R32.1
unnamed: C17.+, JP5.3
unnamed: JP5.1, R35.2
unnamed: R36.2, SJ6.3
unnamed: R37.2, SJ6.1
unnamed: C22.1, U6.2
unnamed: BT6.VCC@1, R42.1
unnamed: JP6.2, R39.1
unnamed: C21.+, JP6.3
unnamed: JP6.1, R42.2
unnamed: R43.2, SJ7.3
unnamed: R44.2, SJ7.1
unnamed: C26.1, U7.2
unnamed: BT7.VCC@1, R49.1
unnamed: JP7.2, R46.1
unnamed: C25.+, JP7.3
unnamed: JP7.1, R49.2
unnamed: R50.2, SJ8.3
unnamed: R51.2, SJ8.1
unnamed: C30.1, U8.2
unnamed: BT8.VCC@1, R56.1
unnamed: JP8.2, R53.1
unnamed: C29.+, JP8.3
unnamed: JP8.1, R56.2
unnamed: R57.2, SJ9.3
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

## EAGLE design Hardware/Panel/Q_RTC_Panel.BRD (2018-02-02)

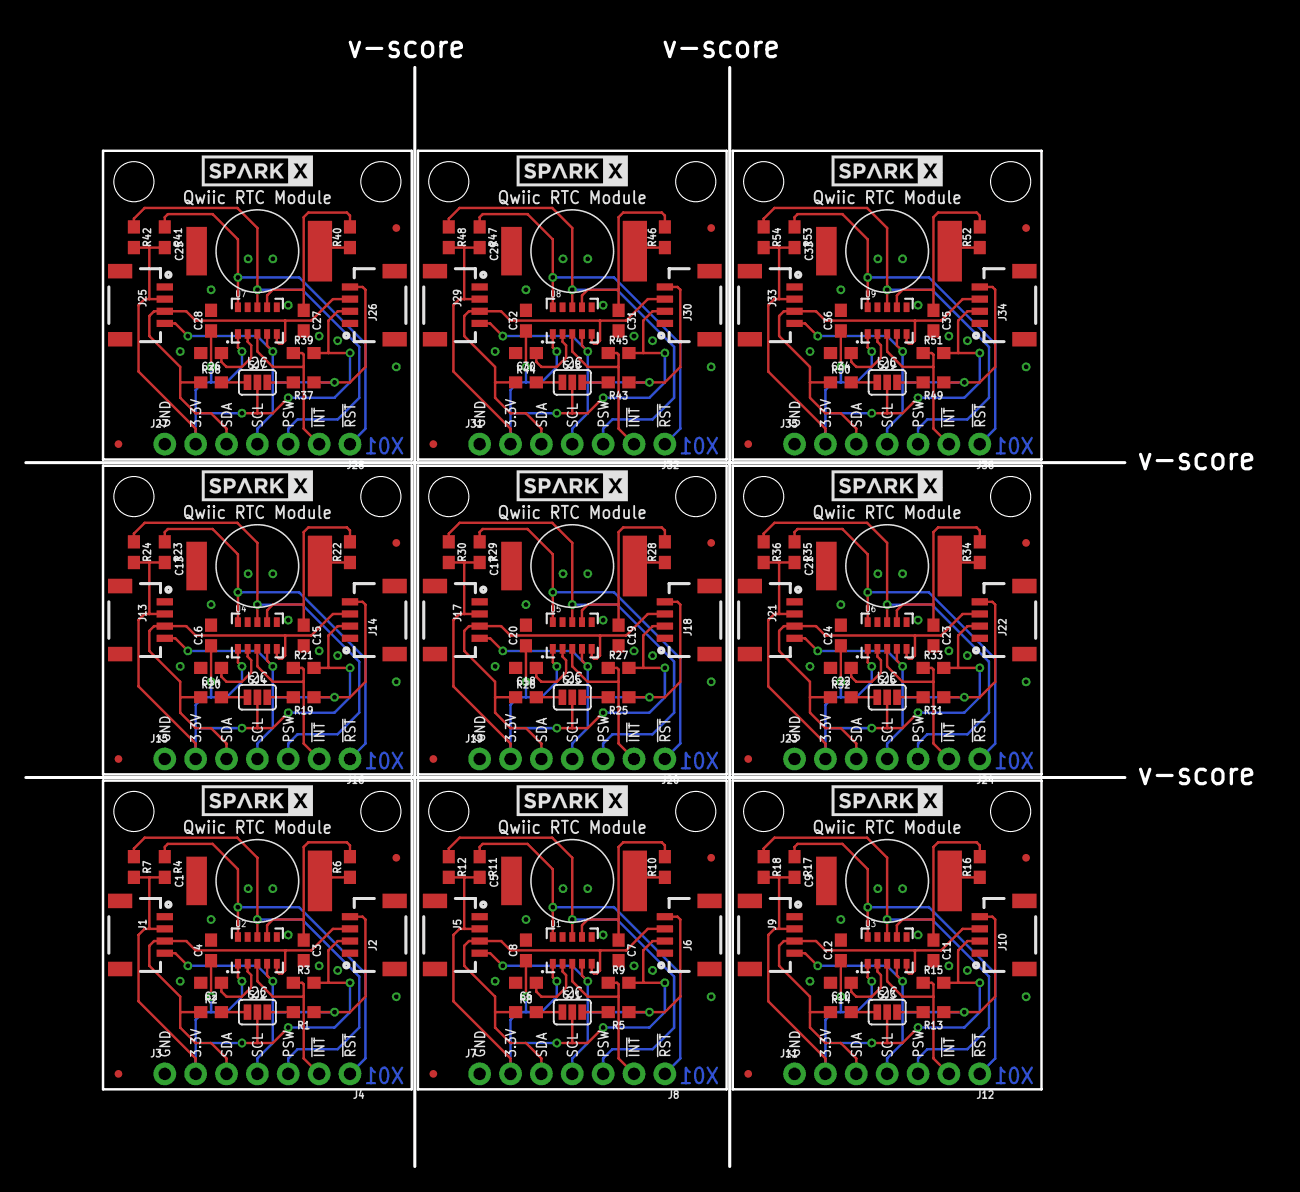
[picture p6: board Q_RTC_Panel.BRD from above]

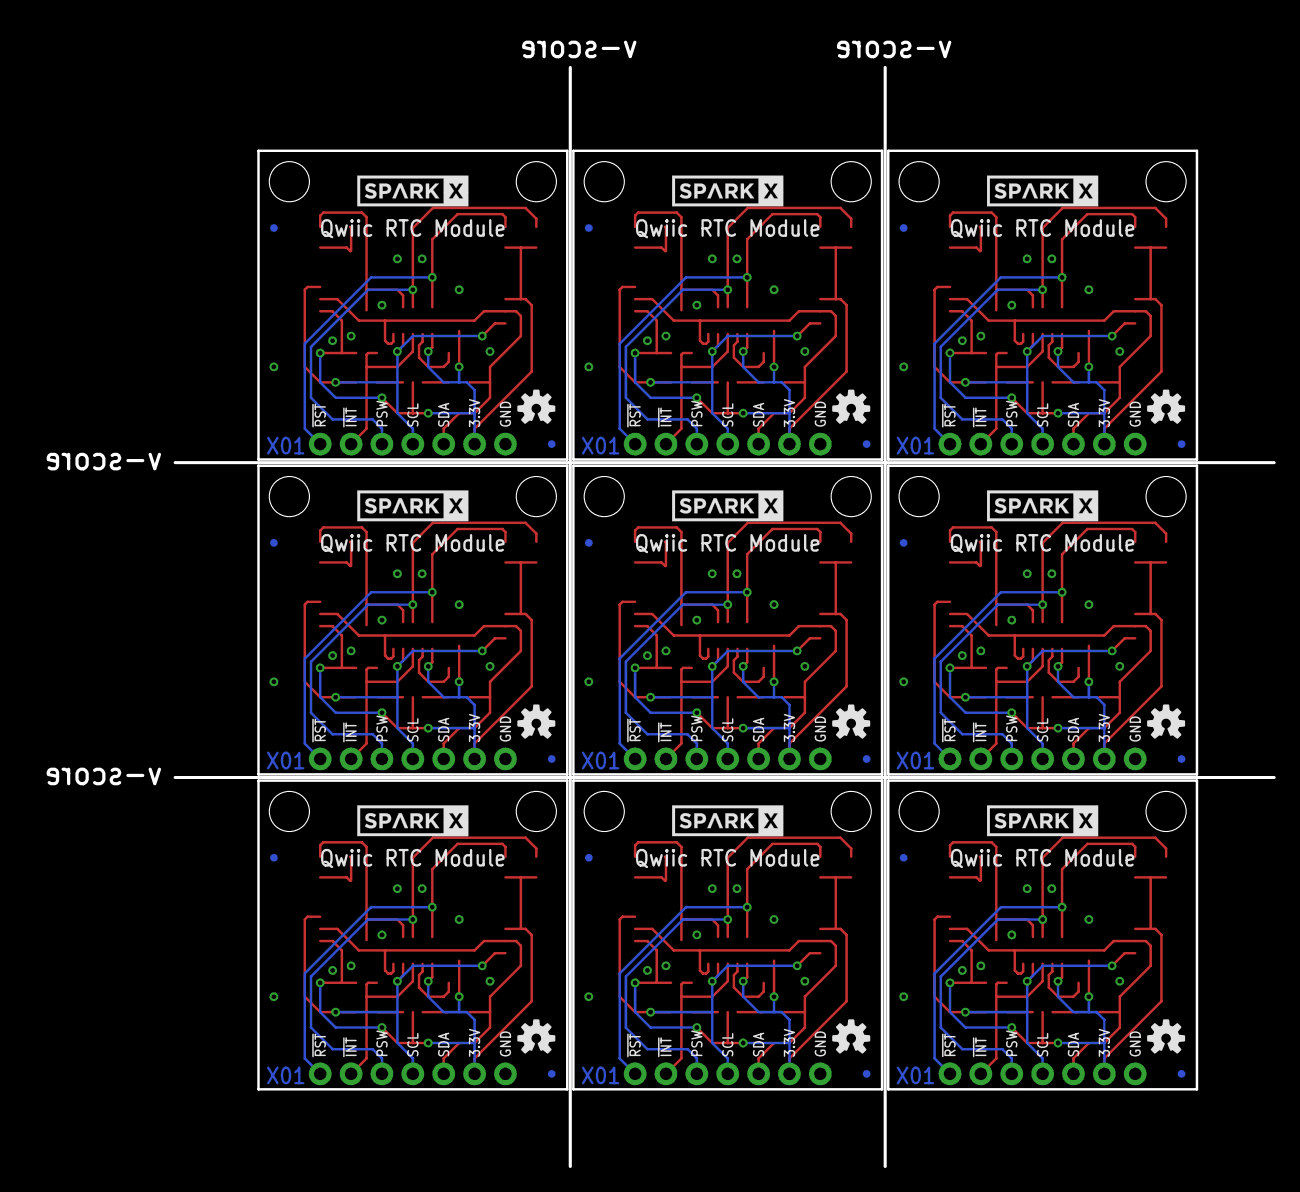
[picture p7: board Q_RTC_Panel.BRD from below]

Board: 2 copper layers, 90.4 x 90.4 mm, 225 parts (36 on the bottom side), 108 nets.

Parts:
C1, C5, C9, C13, C17, C21, C25, C29, C33: .22F-SUPERCAP; DSK-RADIAL-6.8MM
C2, C6, C10, C14, C18, C22, C26, C30, C34: 47pF; 0603
C3, C4, C7, C8, C11, C12, C15, C16, C19, C20, C23, C24, C27, C28, C31, C32, C35, C36: 10nF; 0603
FD1, FD2, FD3, FD4, FD5, FD6, FD7, FD8, FD9, FD10, FD11, FD12, FD13, FD14, FD15, FD16, FD17, FD18, FD19, FD20, FD21, FD22, FD23, FD24, FD25, FD26, FD27, FD28, FD29, FD30, FD31, FD32, FD33, FD34, FD35, FD36: FIDUCIALUFIDUCIAL; FIDUCIAL-MICRO
J1, J2, J5, J6, J9, J10, J13, J14, J17, J18, J21, J22, J25, J26, J29, J30, J33, J34: SMD; 1X04_1MM_RA
J3, J7, J11, J15, J19, J23, J27, J31, J35: PTH; 1X04_NO_SILK
J4, J8, J12, J16, J20, J24, J28, J32, J36: 1X03_NO_SILK
LOGO1, LOGO2, LOGO3, LOGO4, LOGO5, LOGO6, LOGO7, LOGO8, LOGO9: OSHW-LOGOS; OSHW-LOGO-S
R1, R2, R5, R8, R13, R14, R19, R20, R25, R26, R31, R32, R37, R38, R43, R44, R49, R50: 2.2k; 0603
R3, R4, R7, R9, R11, R12, R15, R17, R18, R21, R23, R24, R27, R29, R30, R33, R35, R36, R39, R41, R42, R45, R47, R48, R51, R53, R54: 10k; 0603
R6, R10, R16, R22, R28, R34, R40, R46, R52: 1K; 0603
SJ1, SJ2, SJ3, SJ4, SJ5, SJ6, SJ7, SJ8, SJ9: JUMPER-SMT_3_2-NC_PASTE_SILK; SMT-JUMPER_3_2-NC_PASTE_SILK
U1, U2, U3, U4, U5, U6, U7, U8, U9: RV-1805
U$1, U$2, U$6, U$7, U$9, U$10, U$13, U$14, U$17, U$18, U$21, U$22, U$25, U$26, U$29, U$30, U$33, U$34: STAND-OFF
U$3, U$4, U$5, U$8, U$11, U$12, U$15, U$16, U$19, U$20, U$23, U$24, U$27, U$28, U$31, U$32, U$35, U$36: SPARKX-LOGO4; SPARKX-MEDIUM

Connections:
3.3V: C4.1, J1.2, J2.2, J3.2, R3.2, R4.2, R7.2, SJ2.2, U2.1
3.3V1: C8.1, J5.2, J6.2, J7.2, R9.2, R11.2, R12.2, SJ1.2, U1.1
3.3V2: C12.1, J9.2, J10.2, J11.2, R15.2, R17.2, R18.2, SJ3.2, U3.1
3.3V3: C16.1, J13.2, J14.2, J15.2, R21.2, R23.2, R24.2, SJ4.2, U4.1
3.3V4: C20.1, J17.2, J18.2, J19.2, R27.2, R29.2, R30.2, SJ5.2, U5.1
3.3V5: C24.1, J21.2, J22.2, J23.2, R33.2, R35.2, R36.2, SJ6.2, U6.1
3.3V6: C28.1, J25.2, J26.2, J27.2, R39.2, R41.2, R42.2, SJ7.2, U7.1
3.3V7: C32.1, J29.2, J30.2, J31.2, R45.2, R47.2, R48.2, SJ8.2, U8.1
3.3V8: C36.1, J33.2, J34.2, J35.2, R51.2, R53.2, R54.2, SJ9.2, U9.1
!INT: J4.2, R3.1, U2.3
!INT1: J8.2, R9.1, U1.3
!INT2: J12.2, R15.1, U3.3
!INT3: J16.2, R21.1, U4.3
!INT4: J20.2, R27.1, U5.3
!INT5: J24.2, R33.1, U6.3
!INT6: J28.2, R39.1, U7.3
!INT7: J32.2, R45.1, U8.3
!INT8: J36.2, R51.1, U9.3
!RST: J4.1, R4.1, U2.10
!RST1: J8.1, R11.1, U1.10
!RST2: J12.1, R17.1, U3.10
!RST3: J16.1, R23.1, U4.10
!RST4: J20.1, R29.1, U5.10
!RST5: J24.1, R35.1, U6.10
!RST6: J28.1, R41.1, U7.10
!RST7: J32.1, R47.1, U8.10
!RST8: J36.1, R53.1, U9.10
GND: C1.-, C2.2, C3.2, C4.2, J1.1, J2.1, J3.1, U2.6, U2.9
GND1: C5.-, C6.2, C7.2, C8.2, J5.1, J6.1, J7.1, U1.6, U1.9
GND2: C9.-, C10.2, C11.2, C12.2, J9.1, J10.1, J11.1, U3.6, U3.9
GND3: C13.-, C14.2, C15.2, C16.2, J13.1, J14.1, J15.1, U4.6, U4.9
GND4: C17.-, C18.2, C19.2, C20.2, J17.1, J18.1, J19.1, U5.6, U5.9
GND5: C21.-, C22.2, C23.2, C24.2, J21.1, J22.1, J23.1, U6.6, U6.9
GND6: C25.-, C26.2, C27.2, C28.2, J25.1, J26.1, J27.1, U7.6, U7.9
GND7: C29.-, C30.2, C31.2, C32.2, J29.1, J30.1, J31.1, U8.6, U8.9
GND8: C33.-, C34.2, C35.2, C36.2, J33.1, J34.1, J35.1, U9.6, U9.9
unnamed: R1.2, SJ2.3
unnamed: R2.2, SJ2.1
unnamed: R5.2, SJ1.3
unnamed: C2.1, U2.2
unnamed: C1.+, R6.1
unnamed: R8.2, SJ1.1
unnamed: C6.1, U1.2
unnamed: C5.+, R10.1
unnamed: R13.2, SJ3.3
unnamed: R14.2, SJ3.1
unnamed: C10.1, U3.2
unnamed: C9.+, R16.1
unnamed: R19.2, SJ4.3
unnamed: R20.2, SJ4.1
unnamed: C14.1, U4.2
unnamed: C13.+, R22.1
unnamed: R25.2, SJ5.3
unnamed: R26.2, SJ5.1
unnamed: C18.1, U5.2
unnamed: C17.+, R28.1
unnamed: R31.2, SJ6.3
unnamed: R32.2, SJ6.1
unnamed: C22.1, U6.2
unnamed: C21.+, R34.1
unnamed: R37.2, SJ7.3
unnamed: R38.2, SJ7.1
unnamed: C26.1, U7.2
unnamed: C25.+, R40.1
unnamed: R43.2, SJ8.3
unnamed: R44.2, SJ8.1
unnamed: C30.1, U8.2
unnamed: C29.+, R46.1
unnamed: R49.2, SJ9.3
unnamed: R50.2, SJ9.1
unnamed: C34.1, U9.2
unnamed: C33.+, R52.1
PSW: J4.3, R7.1, U2.8
PSW1: J8.3, R12.1, U1.8
PSW2: J12.3, R18.1, U3.8
PSW3: J16.3, R24.1, U4.8
PSW4: J20.3, R30.1, U5.8
PSW5: J24.3, R36.1, U6.8
PSW6: J28.3, R42.1, U7.8
PSW7: J32.3, R48.1, U8.8
PSW8: J36.3, R54.1, U9.8
SCL: J1.4, J2.4, J3.4, R1.1, U2.4
SCL1: J5.4, J6.4, J7.4, R5.1, U1.4
SCL2: J9.4, J10.4, J11.4, R13.1, U3.4
SCL3: J13.4, J14.4, J15.4, R19.1, U4.4
SCL4: J17.4, J18.4, J19.4, R25.1, U5.4
SCL5: J21.4, J22.4, J23.4, R31.1, U6.4
SCL6: J25.4, J26.4, J27.4, R37.1, U7.4
SCL7: J29.4, J30.4, J31.4, R43.1, U8.4
SCL8: J33.4, J34.4, J35.4, R49.1, U9.4
SDA: J1.3, J2.3, J3.3, R2.1, U2.5
SDA1: J5.3, J6.3, J7.3, R8.1, U1.5
SDA2: J9.3, J10.3, J11.3, R14.1, U3.5
SDA3: J13.3, J14.3, J15.3, R20.1, U4.5
SDA4: J17.3, J18.3, J19.3, R26.1, U5.5
SDA5: J21.3, J22.3, J23.3, R32.1, U6.5
SDA6: J25.3, J26.3, J27.3, R38.1, U7.5
SDA7: J29.3, J30.3, J31.3, R44.1, U8.5
SDA8: J33.3, J34.3, J35.3, R50.1, U9.5
VBACKUP: C3.1, R6.2, U2.7
VBACKUP1: C7.1, R10.2, U1.7
VBACKUP2: C11.1, R16.2, U3.7
VBACKUP3: C15.1, R22.2, U4.7
VBACKUP4: C19.1, R28.2, U5.7
VBACKUP5: C23.1, R34.2, U6.7
VBACKUP6: C27.1, R40.2, U7.7
VBACKUP7: C31.1, R46.2, U8.7
VBACKUP8: C35.1, R52.2, U9.7

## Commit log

2017-12-13 Board ready for design review
    [RTC-Module.brd, RTC-Module.sch]
2017-12-21 post design review changes
    [RTC-Module.brd, RTC-Module.sch]
2017-12-27 fixed checklist issues
    [RTC-Module.sch]
2018-01-24 updated sensor
    [RTC-Module.brd, RTC-Module.sch]
2018-01-25 Updated RTC module
    [RTC-Module.brd, RTC-Module.sch]
2018-01-31 updated to RV-1805
    [RTC-Module.brd, RTC-Module.sch]
2018-01-31 updated cap value
    [RTC-Module.brd, RTC-Module.sch]
2018-02-01 Updated cap footprint, broke out rest of pins
    [RTC-Module.brd, RTC-Module.sch]
2018-02-02 Moved via
    [RTC-Module.brd]
2018-02-02 Changed pull ups, super cap silk, added panel.
    Removed dupicate resistor on super cap. Removed pin 1 silk on super cap. Change I2C pull ups to 2.2k for 3.3V devices. Changed pull ups to 10k for lower draw. Added panel.
    [Q_RTC_Panel.BRD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]
2018-02-09 laying out with battery
    [RTC-Module.brd, RTC-Module.sch]
2018-02-12 added battery footprint, went through engineering checklist
    [RTC-Module.brd, RTC-Module.sch]
2018-02-14 post review changes
    [RTC-Module.brd]
2018-02-15 Qwiic RTC silk change
    [RTC-Module.brd]
2018-02-28 order protos, fix resistor PROD_ID
    [RTC-Module.GBL, RTC-Module.GBO, RTC-Module.GBS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]
2018-03-07 post checklist changes
    [RTC-Module.brd, RTC-Module.sch]
2018-03-12 updated battery package
    [RTC-Module.brd, RTC-Module.sch]
2018-03-12 created panel v10
    [RTC-Module-Panel_v10.brd]

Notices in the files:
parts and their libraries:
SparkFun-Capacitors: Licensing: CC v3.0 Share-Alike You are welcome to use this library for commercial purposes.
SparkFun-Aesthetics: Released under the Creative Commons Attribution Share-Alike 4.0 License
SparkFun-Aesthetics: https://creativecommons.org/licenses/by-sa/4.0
